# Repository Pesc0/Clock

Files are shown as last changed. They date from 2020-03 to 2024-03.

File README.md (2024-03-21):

# Clock
A digital clock based on the AtTiny85 and DS3231 chips.

### Features:
 * Simple interface, designed for the elderly who just need a simple clock.
 * Time is kept even after a power loss, provided the battery is working.
 * Great time keeping accuracy, thanks to the 2ppm accuracy of the DS3231 chip (basically in the worse case it will gain/lose 1 minute every year).
 * Brightness can be adjusted, the value is saved and will be restored even after a complete power loss.
 * Can display ambient temperature (the value is updated internally every minute or so).
 * Easy to build PCB, ideal for beginners.
 * Cheap, around $10.
 * The display consumes most of the power, so in theory it's possible to run the clock on batteries [not tested]. 
 * Fully open source.

## PCB Design
Things to note:
- The board is symmetrical to simplify the design of mounting mechanisms.
- The button panel is "removable" from the main pcb body, to allow repositioning of the buttons.
- On the board are present two jumpers that disconnect the ATTiny from the I2C bus, for debug purposes.

## 3D printed case
TBD

## Building and Flashing the firmware

You will need a working avr toolchain, with `avr-gcc` and `avrdude` installed on your computer. They are very easy to install on a linux computer, but on windows you will have to fiddle with Arduino IDE.
You will also need an AVR programmer, or alternatively you can use "Arduino as ISP". 
You may need to modify the makefile and replace /dev/ttyACM0 with the usb port where your ICSP programmer is connected.

Once the programmer is connected to the board simply run  
``` 
make install 
```

# Gallery
<p align="center">
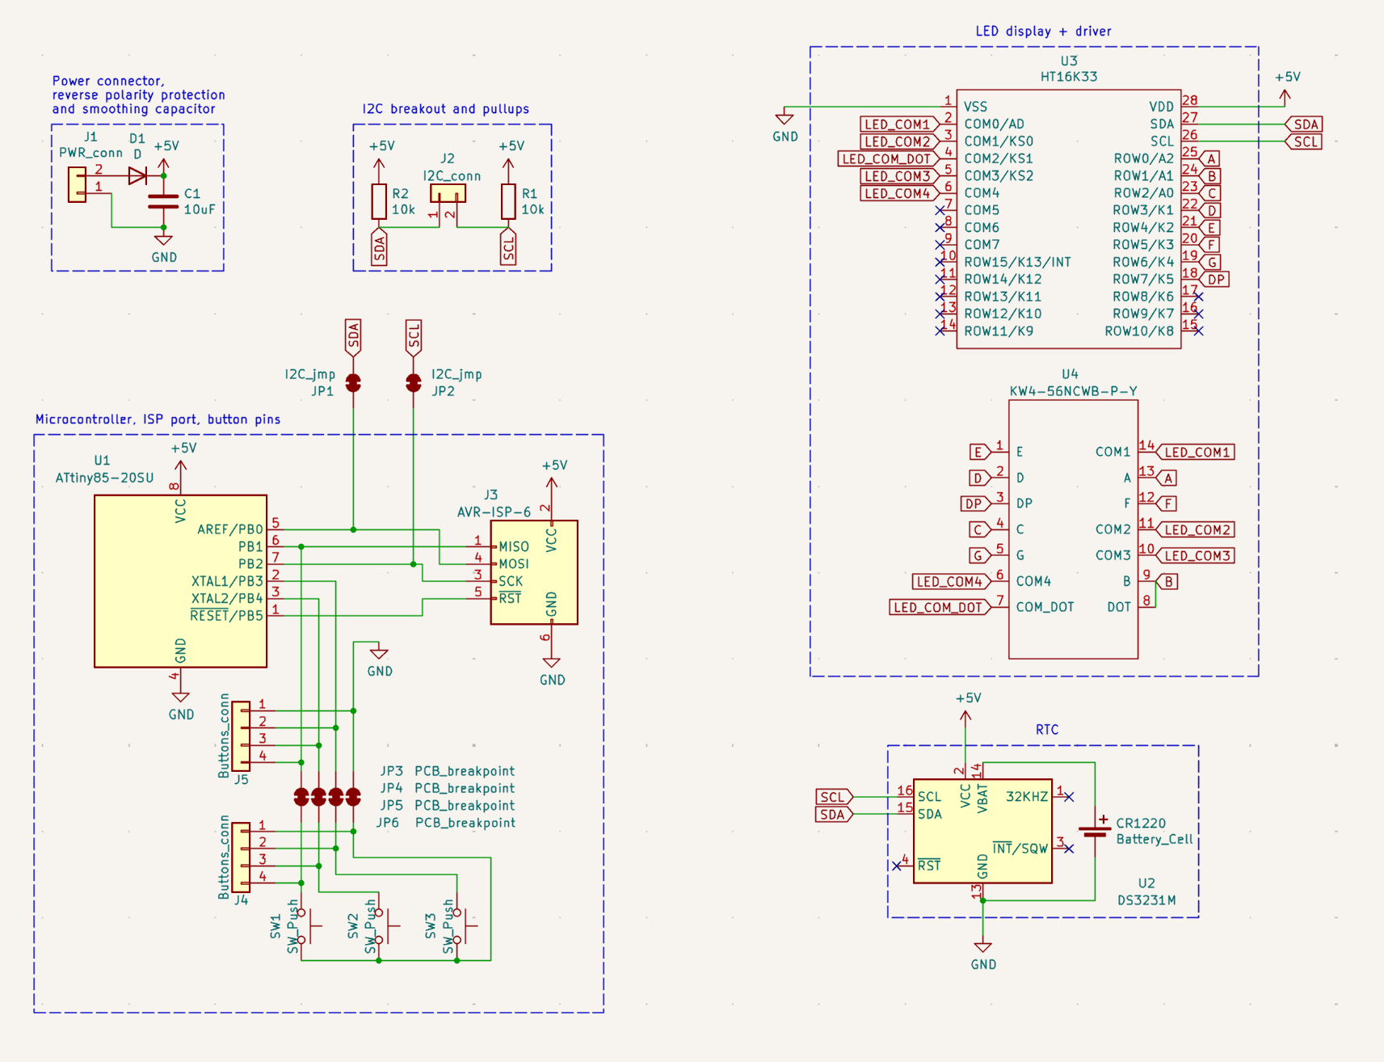
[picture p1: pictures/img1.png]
  
</p>

<p align="center">
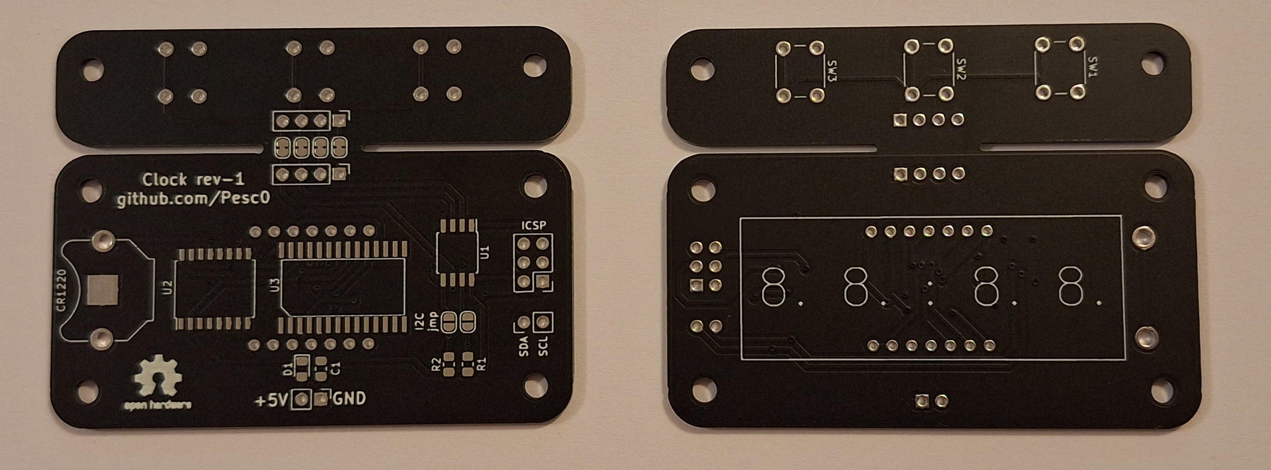
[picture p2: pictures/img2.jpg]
  
</p>

<p align="center">
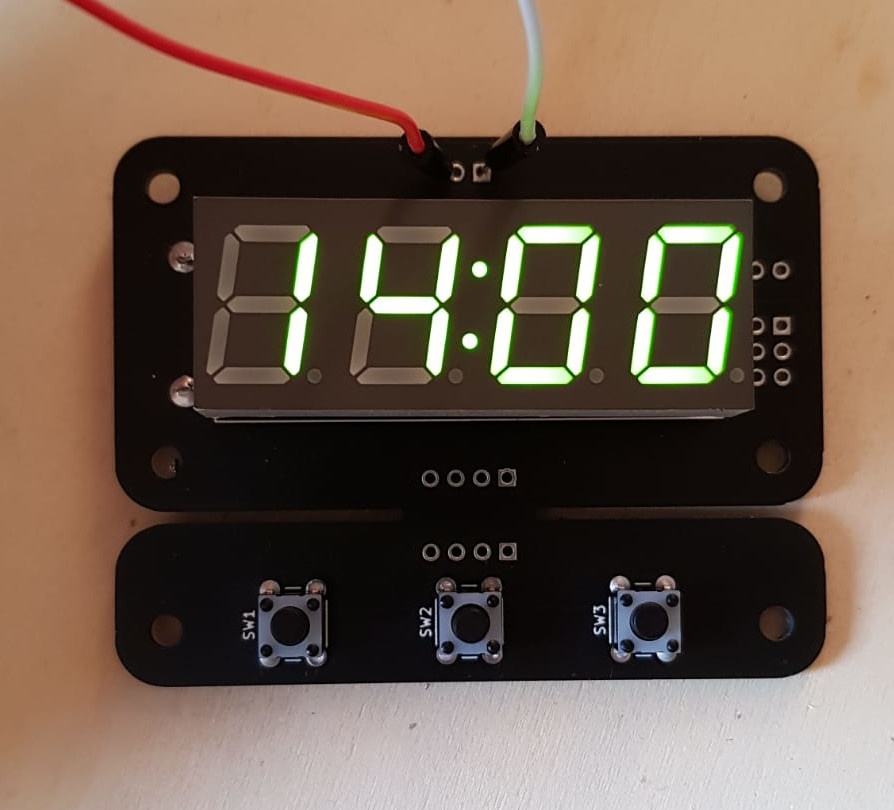
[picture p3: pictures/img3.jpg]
  
</p>

# Revisions
- rev-1: initial design
- rev-2: fix display was upside down, despite silkscreen being right side up

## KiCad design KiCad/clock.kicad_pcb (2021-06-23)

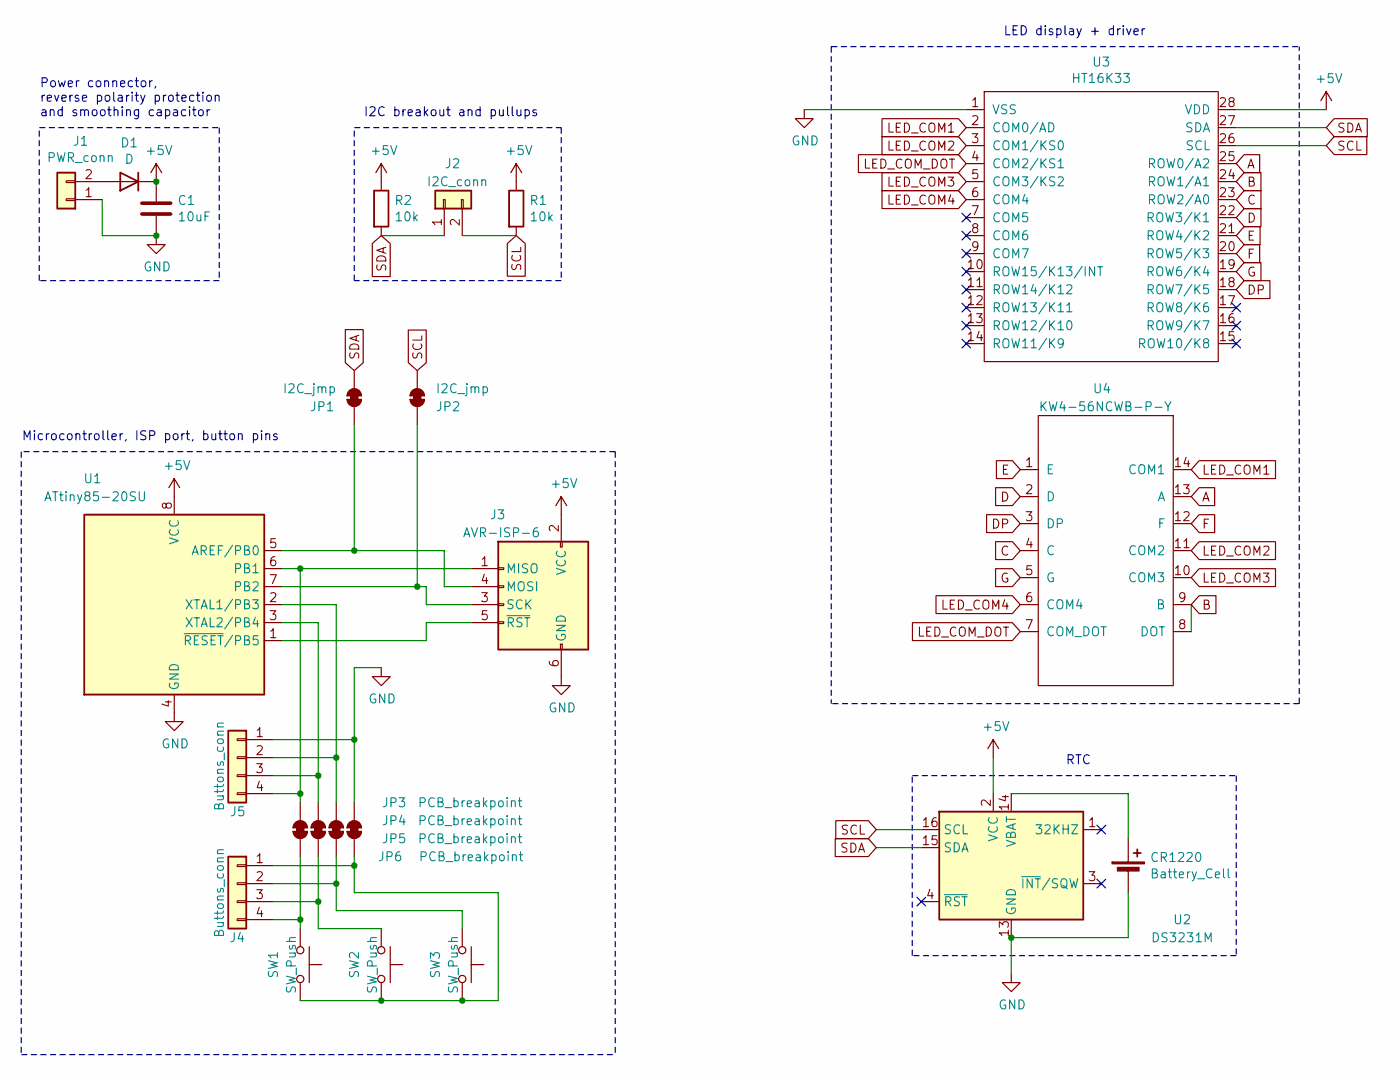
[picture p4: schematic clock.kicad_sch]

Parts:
C1: 10uF; C_0805_2012Metric_Pad1.15x1.40mm_HandSolder
CR1220: Battery_Cell; BatteryHolder_Keystone_3001_1x12mm
D1: D; D_0805_2012Metric_Pad1.15x1.40mm_HandSolder
J1: PWR_conn; PinHeader_1x02_P2.54mm_Vertical
J2: I2C_conn; PinHeader_1x02_P2.54mm_Vertical
J3: AVR-ISP-6; PinHeader_2x03_P2.54mm_Vertical
J4, J5: Buttons_conn; PinHeader_1x04_P2.54mm_Vertical
JP1, JP2: I2C_jmp; SolderJumper-2_P1.3mm_Bridged_RoundedPad1.0x1.5mm
JP3, JP4, JP5, JP6: PCB_breakpoint; SolderJumper-2_P1.3mm_Bridged_RoundedPad1.0x1.5mm
R1, R2: 10k; R_0805_2012Metric_Pad1.15x1.40mm_HandSolder
SW1, SW2, SW3: SW_Push; SW_PUSH_6mm
U1: ATtiny85-20SU; SOIJ-8_5.3x5.3mm_P1.27mm
U2: DS3231M; SOIC-16W_7.5x10.3mm_P1.27mm
U3: HT16K33
U4: KW4-56NCWB-P-Y; 7segment

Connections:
+5V: C1.1, D1.1 (K), J3.2 (VCC), R1.1, R2.1, U1.8 (VCC), U2.2 (VCC), U3.28 (VDD)
A: U3.25 (ROW0/A2), U4.13 (A)
B: U3.24 (ROW1/A1), U4.8 (DOT), U4.9 (B)
C: U3.23 (ROW2/A0), U4.4 (C)
D: U3.22 (ROW3/K1), U4.2 (D)
DP: U3.18 (ROW7/K5), U4.3 (DP)
E: U3.21 (ROW4/K2), U4.1 (E)
F: U3.20 (ROW5/K3), U4.12 (F)
G: U3.19 (ROW6/K4), U4.5 (G)
GND: C1.2, CR1220.2 (-), J1.1, J3.6 (GND), J5.1, JP6.1 (A), U1.4 (GND), U2.5 (GND), U2.6 (GND), U2.7 (GND), U2.8 (GND), U2.9 (GND), U2.10 (GND), U2.11 (GND), U2.12 (GND), U2.13 (GND), U3.1 (VSS)
LED_COM1: U3.2 (COM0/AD), U4.14 (COM1)
LED_COM2: U3.3 (COM1/KS0), U4.11 (COM2)
LED_COM3: U3.5 (COM3/KS2), U4.10 (COM3)
LED_COM4: U3.6 (COM4), U4.6 (COM4)
LED_COM_DOT: U3.4 (COM2/KS1), U4.7 (COM_DOT)
unnamed: CR1220.1 (+), U2.14 (VBAT)
unnamed: D1.2 (A), J1.2
unnamed: J3.1 (MISO), J5.4, JP3.1 (A), U1.6 (PB1)
unnamed: J3.3 (SCK), JP2.2 (B), U1.7 (PB2)
unnamed: J3.4 (MOSI), JP1.2 (B), U1.5 (AREF/PB0)
unnamed: J3.5 (~RST), U1.1 (~RESET/PB5)
unnamed: J4.1, JP6.2 (B), SW1.2, SW2.2, SW3.2
unnamed: J4.2, JP5.2 (B), SW3.1
unnamed: J4.3, JP4.2 (B), SW2.1
unnamed: J4.4, JP3.2 (B), SW1.1
unnamed: J5.2, JP5.1 (A), U1.2 (XTAL1/PB3)
unnamed: J5.3, JP4.1 (A), U1.3 (XTAL2/PB4)
SCL: J2.2, JP2.1 (A), R1.2, U2.16 (SCL), U3.26 (SCL)
SDA: J2.1, JP1.1 (A), R2.2, U2.15 (SDA), U3.27 (SDA)

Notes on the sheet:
Microcontroller, ISP port, button pins
I2C breakout and pullups
RTC
LED display + driver
Power connector, reverse polarity protection and smoothing capacitor

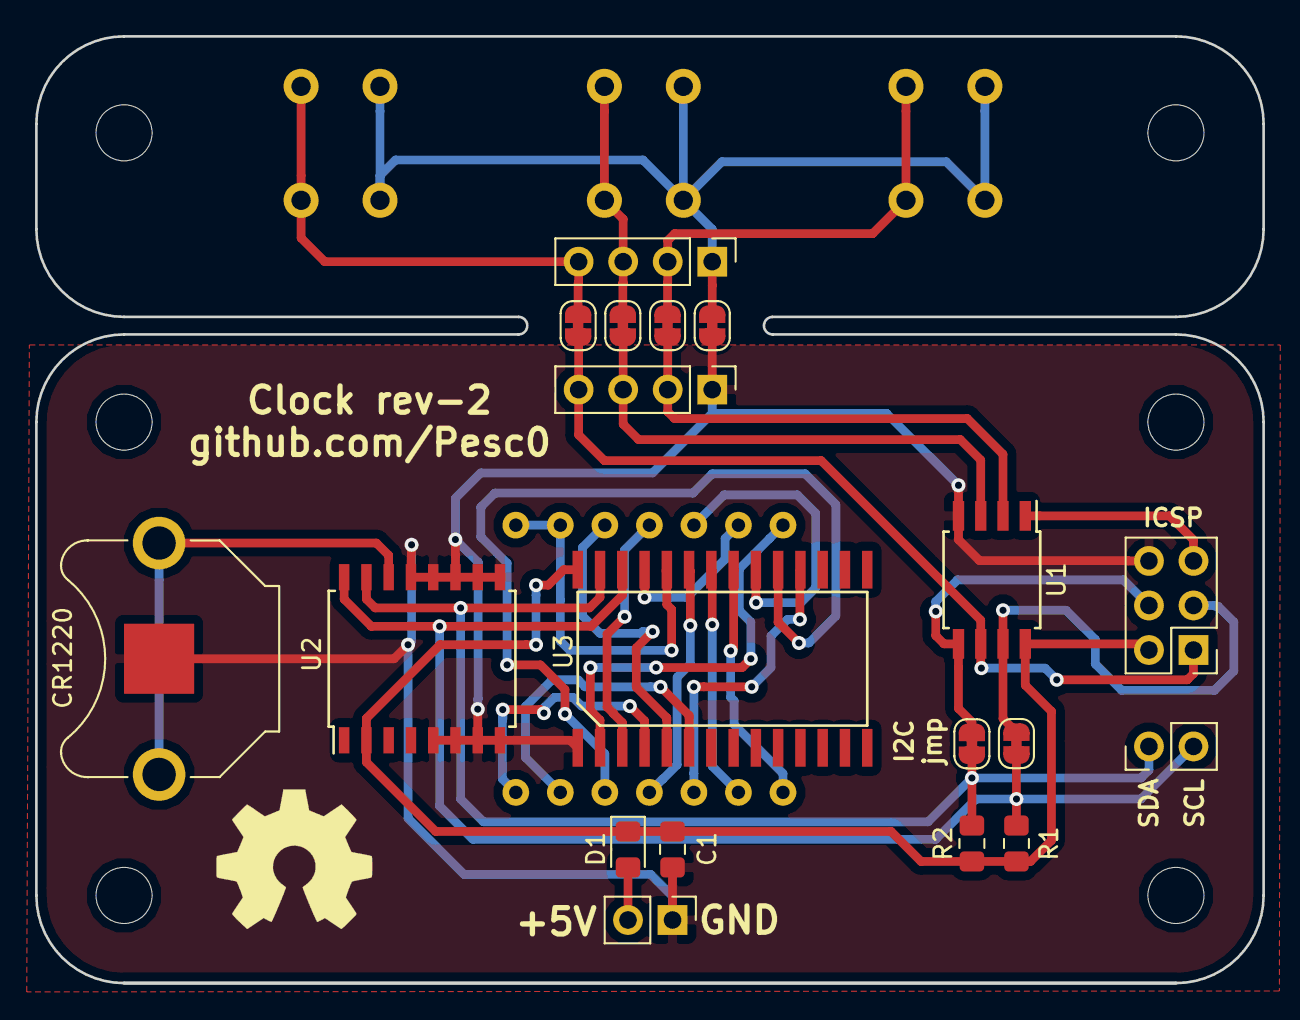
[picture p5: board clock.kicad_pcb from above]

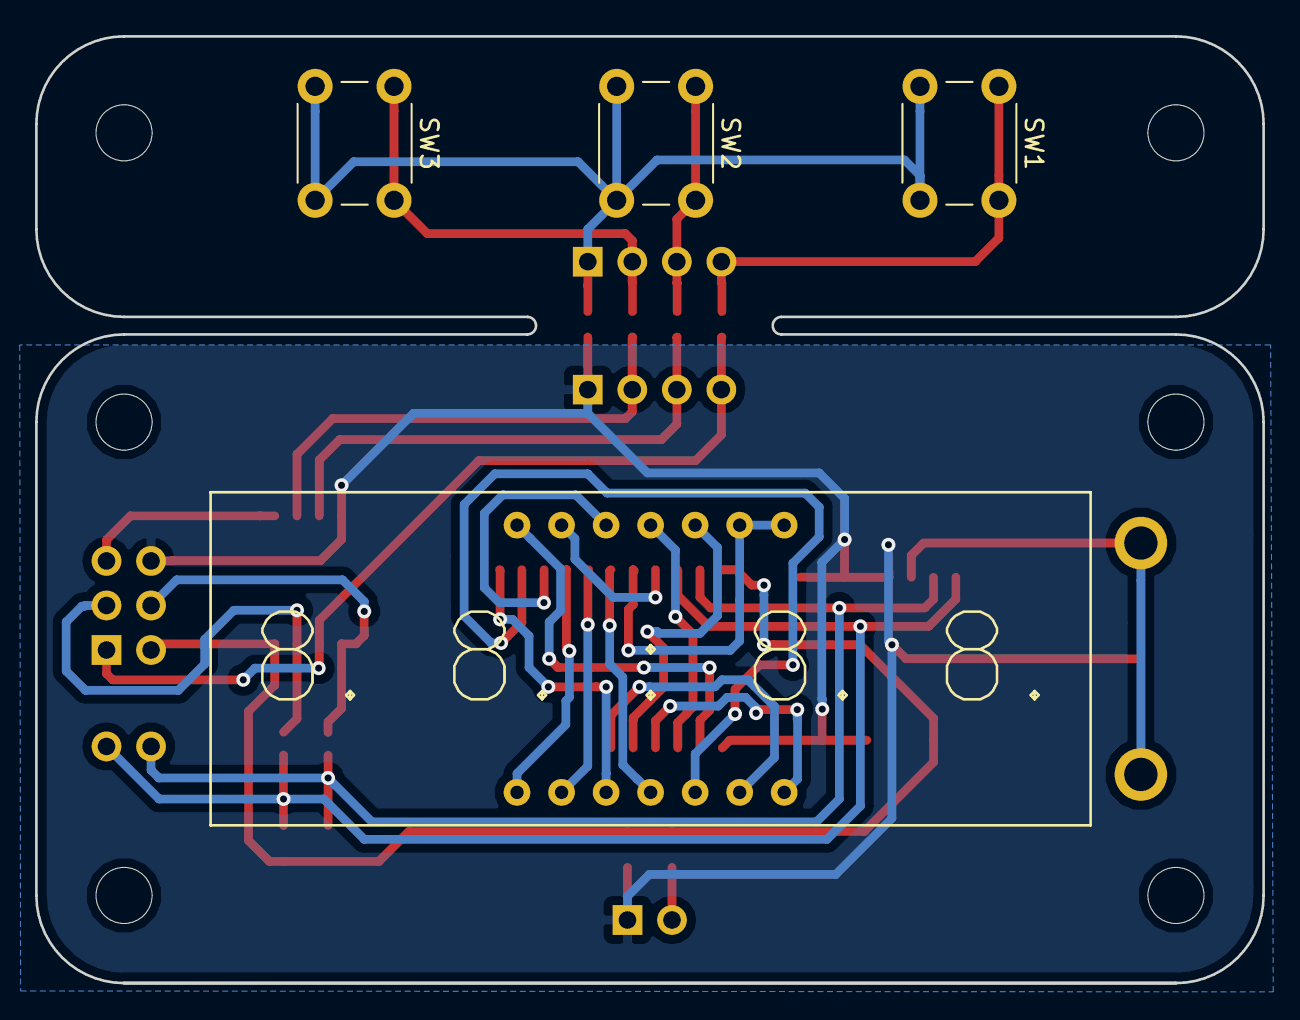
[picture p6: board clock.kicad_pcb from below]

Board: 2 copper layers, 70.0 x 54.0 mm, 23 parts (4 on the bottom side), 29 nets.

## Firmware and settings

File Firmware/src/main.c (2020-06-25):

#include "USI_I2C_Master.h"
#include "DS3231.h"
#include "HT16K33_display.h"
#include "eeprom.h"
#include "buttons.h"
#include "clock.h"
#include "config.h"


#include <avr/interrupt.h>
#include <avr/wdt.h>
#include <avr/sleep.h>


int main()
{
    I2C_init();
    disp_init();
    RTC_init();
    clock_init();
    buttons_init();

    /* power saving */
    ADCSRA &= ~(1 << ADEN); //disable adc
    ACSR = (1 << ACD); //disable analog comparator
    PRR |= (1 << PRTIM1) | (1 << PRTIM0) | (1 << PRADC); //disable adc and timers. 
    //for convenience leave usi active to avoid having to re initialize it

    set_sleep_mode(SLEEP_MODE_PWR_DOWN); //setup to enter sleep mode
    sleep_enable();

    while(true) 
    {

        //temporarily disable interrupts to allow timed sequence to disable bod during sleep
        cli(); 
        sleep_bod_disable(); 
        sei();

        sleep_cpu(); //go to sleep and wait for an interrupt. 

        //after the interrupt has woken up the cpu and executed the loop will restart
    }

    return 0; //never reached
}

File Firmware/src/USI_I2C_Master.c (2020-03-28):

#include "USI_I2C_Master.h"

#include <avr/io.h>
#include <util/delay.h>


#define USI_PORT PORTB
#define USI_DDR DDRB
#define USI_PIN PINB

#define SDA PB0
#define SCL PB2

#define FAST_MODE

/*---------------------*/

inline void SDA_HI() { USI_PORT |= (1 << SDA); }
inline void SCL_HI() { USI_PORT |= (1 << SCL); }
inline void SDA_LO() { USI_PORT &= ~(1 << SDA); } 
inline void SCL_LO() { USI_PORT &= ~(1 << SCL); } 

inline void SDA_IN() { USI_DDR &= ~(1 << SDA); } 
inline void SDA_OUT() { USI_DDR |= (1 << SDA); }

inline void toggle_SCL() { USICR |= (1 << USITC); }
inline void wait_SCL_HI() { while( !(USI_PIN & (1 << SCL)) ); }

#ifdef FAST_MODE
    //Delays for fast mode (100kHz < SCL < 400kHz)
    static inline void delay_T2() { _delay_us(2); } // > 1.3us
    static inline void delay_T4() { _delay_us(1); } // > 0.6us
#else
    //Delays for standard mode (SCL <= 100kHz)
    static inline void delay_T2() { _delay_us(5); } // > 4.7us
    static inline void delay_T4() { _delay_us(4); } // > 4.0us
#endif

inline void clear_USISR_flags() 
{
    //Read timer bits to keep them unchanged
    uint8_t timer_bits = USISR & ((1 << USICNT3) | (1 << USICNT2) | (1 << USICNT1) | (1 << USICNT0));

    //Write 1 to the flags we want cleared, 0 to keep them unchanged
    uint8_t flag_bits = ((1 << USISIF) | (1 << USIOIF) | (1 << USIPF) | (1 << USIDC));

    //Write prepared data to USISR
    USISR = flag_bits | timer_bits; 
}

inline void reset_USIDR() { USIDR = 0xFF; } //Fill with "released level" data

/*---------------------*/


void I2C_init() 
{
    USI_PORT |= (1 << SDA) | (1 << SCL); //Enable pullups on SDA and SCL.
    USI_DDR |= (1 << SDA) | (1 << SCL); //SDA and SCL set as output

    USICR = (1 << USIWM1) | (1 << USICS1) | (1 << USICLK); //Two wire mode, Software stobe as clock

    reset_USIDR(); //Preload data register with "released level" data.

    clear_USISR_flags(); //Clear any flags
    USISR = (0x0 << USICNT0); //Reset clock counter
}

void transfer() 
{
    clear_USISR_flags(); //Clear flags to later detect stop condition

    do {
        delay_T2();
        toggle_SCL(); //Generate positive SCL edge.
        wait_SCL_HI(); //Wait for SCL to go high.
        delay_T4();
        toggle_SCL(); //Generate negative SCL edge.
    } while ( !(USISR & (1 << USIOIF)) ); //Check for transfer complete.

    delay_T2();
}

void transfer_1bit() 
{
    //Set timer to overflow after 2 clock edges (shift 1 bit)
    USISR = (0xE << USICNT0);
    transfer();
}

void transfer_8bit() 
{
    //Set timer to overflow after 16 clock edges (shift 8 bit)
    USISR = (0x0 << USICNT0);
    transfer();
}


bool gen_start_condition() 
{
    //Release SCL to ensure that (repeated) Start can be performed 
    SCL_HI(); 
    wait_SCL_HI(); //Verify that SCL becomes high.
    delay_T2();

    //Generate start condition
    SDA_LO(); 
    delay_T4();
    SCL_LO(); 
    SDA_HI(); 

    if( !(USISR & (1 << USISIF)) ) { 
        return false; //Failed to detect start condition
    }

    return true;
}

bool gen_stop_condition() 
{
    SDA_LO(); 
    SCL_HI();
    wait_SCL_HI(); //Wait if slave is not ready.
    delay_T4();
    SDA_HI();
    delay_T2();
  
    if( !(USISR & (1 << USIPF)) ) { 
        return false; //Failed to detect stop condition
    }

    return true;
}

void send_ACK() 
{
    USIDR = 0x00; //ACK is 0
    transfer_1bit();
    reset_USIDR();
}

void send_NACK() 
{
    USIDR = 0xFF; //NACK is 1
    transfer_1bit();
    reset_USIDR();
}

bool I2C_init_write(uint8_t address) 
{
    gen_start_condition();

    //Write is 7 address bits and a final 0
    return I2C_write((address << 1) | 0); 
}

bool I2C_write(uint8_t data) 
{
    //Write data
    SCL_LO(); //Pull SCL LOW to modify USIDR.
    USIDR = data; //Setup data.
    transfer_8bit(); 
    reset_USIDR();

    //Check ack/nack response from slave
    SDA_IN(); //SDA as input to read
    transfer_1bit(); //Read ACK/NACK
    data = USIDR; //Reuse data variable to immediately reset data register
    reset_USIDR();
    SDA_OUT(); //Restore as output

    if (data & (1 << 0)) { //NACK is a 1 at position 0
        return false; //Recieved NACK
    }

    return true; //ACK is a 0 at position 0, write successful
}

bool I2C_init_read(uint8_t address) 
{
    gen_start_condition();

    //Read is 7 address bits and a final 1
    return I2C_write((address << 1) | 1);
}

uint8_t read() 
{
    SDA_IN(); //SDA input to read
    transfer_8bit();
    uint8_t data = USIDR;
    reset_USIDR();
    SDA_OUT(); //Restore as output

    return data;
}

uint8_t I2C_read() 
{
    uint8_t data = read();
    send_ACK(); //Keep reading
    return data;
}

uint8_t I2C_read_last() 
{
    uint8_t data = read();
    send_NACK(); //Terminate reading
    return data;
}

void I2C_stop() 
{
    gen_stop_condition();
}

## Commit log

2021-06-23 Added PCB Files
    [clock-B.Cu.gbl, clock-B.Cu.gbr, clock-B.Mask.gbr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]
2021-06-23 moved gerber files
    [clock-B.Cu.gbl, clock-B.Cu.gbr, clock-B.Mask.gbr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]
2024-03-21 Update kicad version
    [clock.kicad_sch]
